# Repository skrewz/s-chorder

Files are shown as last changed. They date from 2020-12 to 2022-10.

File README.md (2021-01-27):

# s-chorder

This is a [chording keyboard project](https://en.wikipedia.org/wiki/Chorded_keyboard). In short, it's a device that allows you to type one-handed and with minimal movement.

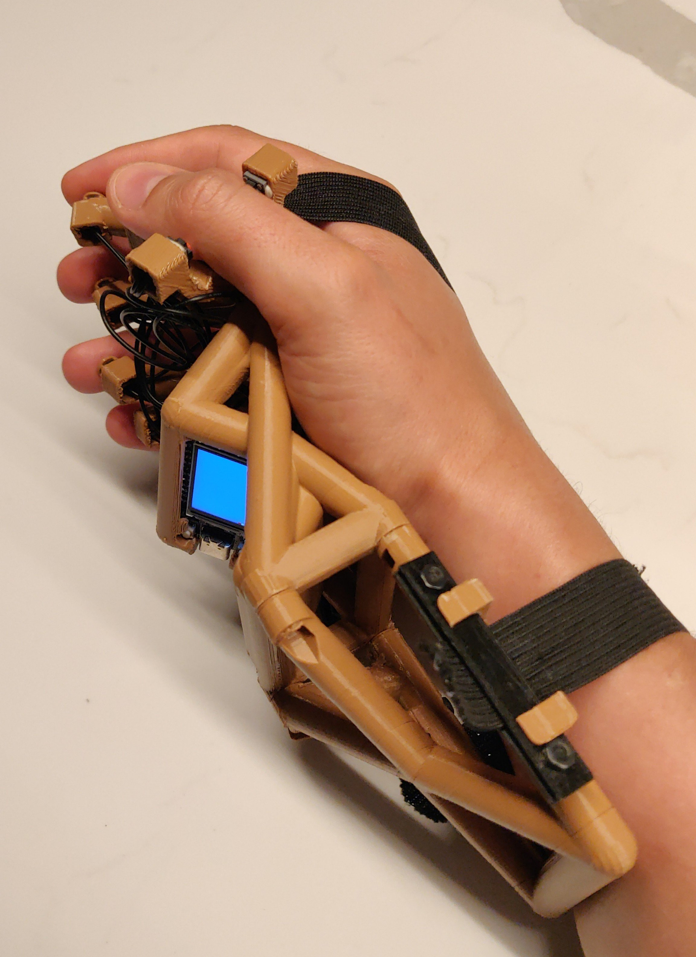
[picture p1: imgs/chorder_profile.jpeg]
chorder_profile Chorder in profile


## Why?

Chording keyboards fill certain niches.

* They are perfect for wearable computing which [Greg Priest-Dorman has practised for a number of years](https://www.cs.vassar.edu/people/priestdo/wearables/top). Indeed, his and [Mikkel Holm Olsen's SpiffChorder](https://chorder.cs.vassar.edu/doku.php?id=spiffchorder:hardware) served as inspiration for this project.
* They allow usage in the blind. This opens up for certain use cases, including note taking in the dark and in situations calling for inconspicuousness (if you can get past the bit about having something attached to your hand, that is).
* They can aid people with RSI related injuries by providing an alternative typing system, or a system that makes use of a remaining limb.

# How would I go about making one myself?

The model OpenSCAD file [is parametric to a ridiculous degree](https://github.com/skrewz/s-chorder/blob/master/chorder.scad#L33-L71). The idea is that one is supposed to be able to plop one's own measurements into it, and it'd generate a 3D model that fits a hand with such measurements. We may, however, have strayed from that ideal at this point, and yours truly, by the nature of things, has only had the need to produce models for one specific geometry.

If you find yourself trying this out, I'd recommend one of two approaches, or a combination of them:

1. Try measuring your finger segment lengths. They are measured on a bent finger (i.e. one that exposes 90 degree angles on both ends of the segment) and measured like a caliper would; externally. The finger radii should handle the difference from external measurement to where the joint pivots. This might provide a starting point, but, ultimately, you'll also be...:
2. Find some economic slicing settings for your slicer and acknowledge you will get it wrong. I find that it's worth printing another version even for single millimetres of incorrect location, so it pays to print a whole lot of single-shelled-5%-infill sorts of budget prints.

At any rate, make sure you make a git commit in your fork for every time you print a prototype. This'll help greatly in terms of knowing what you've changed. And please let me know what sort of tweaks you've had to do—maybe it can be better integrated into the model's calculations.

## Actually printing it

The `finger_end` will need a lot of support. It's essentially printed on supports. I've had good mileage with two raft layers and playing with Prusa-Slic3r's support enforcers.

The `body` and `wrist_handle` can be printed standing on their connecting surfaces, although the `body` is likely to need a fair bit of support for the bits that eventually will be under the index finger.

The `body` and `finger_end` modules derive their connection points from the same finger geometry measurements, so if they change, you'll likely need to print a new version of both. The `wrist_handle` module is fairly fixed and won't need much fine-tuning.

## Electronics and firmware

I would recommend using a TTGO T-Display for this project. It has battery capability, charges off USB-C and allows some nice features surrounding note-taking. I bought [this product for the project](https://www.aliexpress.com/item/1005001343590866.html).

The model is based on 6mm×6mm buttons (seemingly for computer mice?). I used [these ones from AliExpress](https://www.aliexpress.com/item/32653516999.html). The straps are made from the elastic/silicone tape that's meant to be sown into garments for invisible hold. You'll probably also want to solder some long-ish Dupont cables.

I've developed [a firmware for my purposes](https://github.com/skrewz/esp-idf-chorderfw). It's a bit of a work in progress, though.

# Contact

Well. My email address is in the git commit history, right? 🙂

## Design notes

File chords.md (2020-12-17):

# Chord overview

This is laid out for reading for right-hand chorders. It applies in reverse, too.

## Letters and their extra functions

Shifting [F], numbering [N] and "both" are prefix chords. If pressing [CN] together isn't convenient, one can do [N][F] or [F][N], which may be more appropriate for certain hardware.

Empty spots below may have functions; they're omitted because those are better done by other chords.

None    | shifted     | Num  | Both  | Thumb  | Fingers | Hint
--------|-------------|------|-------|--------|---------|-----
[]      | [F]         | [N]  | [CN]  | F C N  | I M R P |
[space] | [space]     | 1    | !     | ◻◼◻    | ◻◻◻◻    |
a       | A           | +    |       | ◻◼◻    | ◼◼◼◻    | **A**ddition
b       | B           | \    | &#124;| ◻◻◻    | ◼◻◻◼    | **B**ackslash
c       | C           | 7    | &     | ◻◼◻    | ◻◼◻◻    |
d       | D           | /    | ?     | ◻◻◻    | ◼◼◻◻    | **D**ivision
e       | E           | =    | +     | ◻◻◻    | ◼◼◼◻    | **E**qual
f       | F           | 9    | (     | ◻◼◻    | ◻◻◻◼    |
g       | G           | 8    | *     | ◻◼◻    | ◻◻◼◻    |
h       | H           | 00   |       | ◻◻◻    | ◻◼◼◻    |
i       | I           | 2    | @     | ◻◻◻    | ◼◻◻◻    |
j       | J           | ()   | ()    | ◻◼◻    | ◼◻◼◻    |
k       | K           | $    | $     | ◻◻◻    | ◼◻◼◻    |
l       | L           | 6    | ^     | ◻◼◻    | ◼◻◻◻    |
m       | M           | *    | *     | ◻◼◻    | ◼◼◻◻    | **M**ultiply
n       | N           |      |       | ◻◼◻    | ◻◼◼◼    |
o       | O           | 0    | )     | ◻◼◻    | ◼◼◼◼    | Zer**o**
p       | P           | %    | %     | ◻◼◻    | ◻◼◼◻    | **P**ercent
q       | Q           | ?    | ?     | ◻◼◻    | ◼◻◼◼    | **Q**uestion
r       | R           | 3    | #     | ◻◻◻    | ◻◼◻◻    |
s       | S           | -    | _     | ◻◻◻    | ◻◼◼◼    | **S**ubtraction
t       | T           | 000  | 000   | ◻◻◻    | ◼◼◼◼    | 
u       | U           | " "  | " "   | ◻◻◻    | ◻◻◼◼    | Two quotation marks and a back-arrow
v       | V           |      |       | ◻◼◻    | ◻◻◼◼    |
w       | W           | 5    |       | ◻◻◻    | ◻◻◻◼    |
x       | X           | &    | &     | ◻◼◻    | ◼◻◻◼    | (an ampersand has a little **x** in it?)
y       | Y           | 4    |       | ◻◻◻    | ◻◻◼◻    |
z       | Z           | `    | ~     | ◻◻◻    | ◼◻◼◼    |

## Common punctuation

None    | Shifted     | Thumb  | Fingers | Hint
--------|-------------|--------|---------|-----
[]      | [F]         | F C N  | I M R P |
;       | :           | ◻◻◼    | ◻◻◼◼    |
,       | <           | ◻◻◼    | ◻◼◻◻    | **C**omma
.       | >           | ◻◻◼    | ◻◼◼◻    | **P**eriod
'       | "           | ◻◻◼    | ◼◼◼◻    | **A**postrophy
(       |             | ◻◻◻    | ◼◼◻◼    |
[       |             | ◻◼◻    | ◼◼◻◼    |
{       |             | ◻◻◼    | ◼◼◻◼    |
)       |             | ◻◻◻    | ◻◼◻◼    |
]       |             | ◻◼◻    | ◻◼◻◼    |
}       |             | ◻◻◼    | ◻◼◻◼    |

## Media control

None    | Shifted     | Thumb  | Fingers | Hint
--------|-------------|--------|---------|-----
[]      | [F]         | F C N  | I M R P |
🕪       |             | ◼◼◻    | ◻◻◼◼    |
🕩       |             | ◼◼◻    | ◼◼◻◻    |
⏹️       |             | ◼◼◻    | ◻◼◻◻    |
⏯️￼      |             | ◼◼◻    | ◻◼◼◻    |
⏭️￼      |             | ◼◼◻    | ◻◼◼◼    |
⏮️￼      |             | ◼◼◻    | ◼◻◻◼    |
⏮️￼      |             | ◼◼◻    | ◼◼◼◻    |

## Common special keys

(It is possible to obtain numpad equivalents with a [CF] prefix, but ignored for now.)

Plain        | Thumb  | Fingers | Hint
-------------|--------|---------|-----
[]           | F C N  | I M R P |
`Enter`      | ◼◻◻    | ◻◻◻◼    |
`Backspace`  | ◼◻◻    | ◻◼◻◻    |
←            | ◼◻◻    | ◼◻◻◻    |
↓            | ◼◻◻    | ◻◻◼◼    |
↑            | ◼◻◻    | ◼◼◻◻    |
→            | ◼◻◻    | ◻◻◼◻    |
`Home`       | ◼◻◻    | ◼◻◼◼    |
`End`        | ◼◻◻    | ◼◻◻◼    |
`Tab`        | ◼◻◻    | ◼◻◼◻    |
`Left shift` | ◼◻◻    | ◻◻◻◻    |
`Caps lock`  | ◼◻◻    | ◼◼◼◼    |
`Page up`    | ◼◻◻    | ◼◼◼◻    |
`Page down`  | ◼◻◻    | ◻◼◼◼    |

## Common mode-setting/miscellanea chords

Plain          | Thumb  | Fingers | Note
---------------|--------|---------|-----
[]             | F C N  | I M R P |
`GUI`          | ◻◻◼    | ◼◻◼◻    | Prefix
`Esc`          | ◻◻◼    | ◻◻◼◻    | Not a prefix
`Ctrl`         | ◻◻◼    | ◼◻◼◼    | Prefix
`Alt`          | ◻◻◼    | ◻◼◼◼    | Prefix
`Insert`       | ◻◻◼    | ◼◻◻◼    | Not a prefix

## Less frequent special keys

Plain          | Thumb  | Fingers | Hint
---------------|--------|---------|-----
[]             | F C N  | I M R P |
`Delete`       | ◼◻◻    | ◻◼◼◻    |
`Scroll Lock`  | ◼◻◻    | ◼◼◻◼    |
`Print Screen` | ◼◻◻    | ◻◼◻◼    |
↖              | ◼◻◻    | ◼◻◼◼    |
↗              | ◼◻◻    | ◼◼◼◻    |
↘              | ◼◻◻    | ◻◼◼◼    |
↙              | ◼◻◻    | ◼◻◻◼    |
`Numlock`      | ◻◼◼    | ◼◼◼◼    |
Chorder reset  | ◼◼◼    | ◻◻◻◻    | Resets internal state of chorder
`F` key prefix | ◻◻◼    | ◻◻◻◼    |

# Acknowledgements

This is essentially the spiffchorder.

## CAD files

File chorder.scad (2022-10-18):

// TODO: Whole thing should be much more comprehensively commented
// TODO: test object should have contacts at weird angles
// TODO: test object should include connector_positive/connector_negative
// TODO: model should echo() absolute positions of buttons, relative to some
//       known point (connection point?)

partname = "composition";
// The Makefile scrapes the below, but you can specify partname to be any of
// the below values:
//
// _partname_values composition finger_end finger_l body wrist_handle test_object

/*****************************************************************************/
/* Likely calibration properties                                             */
/*****************************************************************************/

// finger_measurements
//
// For the below, the "first joint" (joint 0) is the one at the base of the
// finger. Most people thus have joints 0, 1 and 2 on their four fingers, and
// joints 0 and 1 on their thumb (I'm not exception).
//
// The "first segment" (segment 0) thus is between joint 0 and joint 1, etc,
// until segment 2, which ends at the tip of the finger (segment 1 in the case
// of a thumb).
//
// Generally, these are measured when joints are bent 90 degrees.
//
// E.g. to measure segment 0 on pinky, you'd clench your fist and look at it
// from below. That way, joint0 and joint1 on pinky will be at an angle of at
// least 90 degrees. Then you put a caliper on those two pinky joints.
//
// (It gets more finger-yoga-like to do this with other joints. You'll probably
// have to use another hand to hold the joint in a slightly overstretched
// position. Or take a guess.)
pinky_segment_lengths  = [ 53,  32, 38 ];
ring_segment_lengths   = [ 65,  40, 41 ];
middle_segment_lengths = [ 69,  44, 41 ];
index_segment_lengths  = [ 65,  39, 41 ];
thumb_segment_lengths  = [ 54,  40 ];

// Radii of each finger:
pinky_radius  =  7.5;
ring_radius   =  9.0;
middle_radius = 10.0;
index_radius  = 10.0;
thumb_radius  = 11.0;

// Angles at joint 0, joint 1 and joint 2, for a "comfortably glove-shaped" hand:
pinky_angles  = [20,37,33];
ring_angles   = [20,60,20];
middle_angles = [15,60,10];
index_angles  = [20,30,10];
thumb_angles  = [0,0];

// Almost-guesstimate: for a fingers-stretched hand, where are the joint 0's?
//
pinky_joint0_offset  = [ 110, -25,-15];
ring_joint0_offset   = [  89, -10,-10];
middle_joint0_offset = [  64,   0,  0];
index_joint0_offset  = [  32,  -2,  0];
thumb_joint0_offset  = [   5, -50,-40];

wristaxis_thumbside_upper_offset  = [  37, -80,-15];
wristaxis_pinkyside_upper_offset  = [  97, -80,-15];
wristaxis_radius = 20;

// four fingers: rotation around y axis:
pinky_joint0_rotation  =  [ 14, -30];
ring_joint0_rotation   = [   9, -10];
middle_joint0_rotation = [  -3,   0];
index_joint0_rotation  = [ -10,   0];
// thumb: rotation around x axis:
thumb_joint0_rotation  = [-110, -90];

// LiPo battery measurements:

lipo_compartment_wdh = [34+1,53+3.5,4.9+1];

// the girth of the riggers that make up the most of the finger mounts
frame_radius = 5;


button_l_thickness = 0.5;
button_l_thin_part_thickness = 0.5;
button_l_offset = 4;
button_l_cutout_thickness = button_l_thickness + 1;

// MCU related measurements:

// (Clearance in the height dimension has to be fairly generous if you're using
// Dupont cables.)
mcu_in_use = "TTGO T-Display";
mcu_wall_w = 1.5;
// Use to press MCU deeper (negative values) into its cutout:
mcu_vertical_indentation = -2;


// Elastic band width:

elastic_band_w = 20;
// measured as compressed, if relevant:
elastic_band_thickness = 1;
elastic_band_clearing_w = 22;
elastic_band_wall_w = 3;

button_hole_overdimension_factor = 1.15;

// how much to depress (in the z direction) contact_{positive,negative} given
// that the contact point is at z=0.
contact_z_depress = 15;
// how much depression of spring before electrical contact is made:
contact_clearance = 4;
// 0.3mm wire diameter 10 mm high 6mm outer diameter springs:
// https://www.aliexpress.com/item/33050149067.html
spring_radius = 3;
spring_height = 10;

// Do we want a GND connector on the body()?
include_gnd_connector = false;

/*****************************************************************************/
/* Less-likely calibration properties                                        */
/*****************************************************************************/



// real m3 radius:
m3_radius = 1.5;
// so that an m3 bolt can be passed through without too much effort:
m3_clear_radius = 1.7;

m3_bolt_visualisation_height = 26;

m3_head_radius = 3; // from memory
m3_head_clear_radius = 3.2; // from memory
m3_nut_clear_radius = 3.4; // When creating $fn=6 cutouts for these
m3_nut_height = 2; // actual height (for visualisation)
m3_nut_clear_height = 4; // When creating $fn=6 cutouts for these
m3_head_height = 2; // from memory
m3_nut_holder_wall_w = 1;


connector_depth = 2;

aux_connector_dimension = frame_radius;
aux_connector_growth_factor = 1.3;
aux_connector_growth_height = 10;
aux_connector_standoff = 7;

// https://www.aliexpress.com/item/32960278288.html
// measured: microswitch_box_wdh = [5.79,12.86,6.16];
microswitch_box_wdh = [5.80+0.4,12.80+0.4,/*choosing measured*/6.16];
// Visually only:
microswitch_box_black_until_h = 3.17;
// Switch expands a bit around the mounting through holes:
microswitch_box_h_at_throughhole = 6.52;
microswitch_pin_wdh = [0.5,0.8,3.18];
microswitch_pin_depths = [
  (12.80-2*5.15)/2,
  (12.80-2*5.15)/2+1*5.15,
  (12.80-2*5.15)/2+2*5.15
];
microswitch_lever_d = 1.42;
// only until the point under the radius; larger for cosmetic purposes
microswitch_lever_l = 14.50-5.00/2;
microswitch_lever_width = 3.6;
// estimate:
microswitch_lever_rest_angle = 20;
microswitch_lever_wheel_wr = [3,5.00/2];
// off the lever clearance:
microswitch_lever_wheel_raise = 1.00; // measured

microswitch_throughhole_r = 0.9; // crummy measurement; not precise
microswitch_throughholes_yzs = [
  [(microswitch_box_wdh[1]-6.50)/2,5.80-5.10],
  [(microswitch_box_wdh[1]-6.50)/2+6.50,5.80-5.10],
];

// the width of the pieces "holding up" the switch in its mount:
microswitch_support_bridge_width = 2;
microswitch_case_wall_w = 2;



// how far down (perspective of joint1 on the thumb) the connection point is placed:
thumb_connection_point_translation_distance = 2*thumb_radius;

// Derive coordinates and rotation vectors:

// Helper functions {{{

// These helper functions calculate the coordinate following a segment, as if
// *_joint0_rotation didn't exist (it can be compensated for, later on).
function x_coord_for(startvec,angle,segment,radius) =
  startvec[0] ; // always same, given no _joint0 rotation.
function y_coord_for(startvec,angle,segment,radius) =
  startvec[1] + cos(angle)*(segment-2*radius);
function z_coord_for(startvec,angle,segment,radius) =
  startvec[2] + sin(-angle)*(segment-2*radius);

function sum(list,i=0) = i<len(list)-1 ? list[i] + sum(list,i+1) : list[i];
assert(sum([ 4, 5, 3]) == 12);
assert(sum([ 4, 1, -1]) == 4);

function rotate_coord(coord,joint0_rotation,relative_to_joint0_offset) =
  [
    // have hypotenuse and angle, want opposite:
    relative_to_joint0_offset[0]-sin(joint0_rotation[0])*(relative_to_joint0_offset[2]-coord[2]),
    coord[1], // remains the same when rotating around y axis
    // have hypotenuse and angle, want adjacent:
    relative_to_joint0_offset[2]-cos(joint0_rotation[0])*(relative_to_joint0_offset[2]-coord[2])
  ];

function coord_for(startvec,angle,segment,radius) =
  [
    x_coord_for(startvec,angle,segment,radius),
    y_coord_for(startvec,angle,segment,radius),
    z_coord_for(startvec,angle,segment,radius)
  ];

// Returns a euler rotation 3-tuple that can be used to rotate something in the
// direction of the vector given:
function rotation_of_vector(v) =
  // {{{
  // Due to OpenSCAD function syntax, the below cannot have interim variables.
  // This was a previous calculation, for reference:
  //
  // rotation_upwards = atan(v[2])/sqrt(pow(v[0],2)+pow(v[1],2)));
  // tangent = (v[1])/(v[0]);
  // rotation_in_plane = atan(tangent) + (0 > (v[0]) ? 180 : 0);
  [
    0,
    90-atan((v[2])/sqrt(pow(v[0],2)+pow(v[1],2))),
    // possible corner case: what about _minus_ infinity?
    (is_num(atan(v[1]/v[0])) ? atan(v[1]/v[0]) + (0 > (v[0]) ? 180 : 0) : 90)
  ];
  // }}}

// Applies euler rotation 3-tuple rotations by way of matrix multiplication.
// This function's output is multiplied onto a vector of [0,0,length].
function rotation_for_euler_rotations(a) =
    [[cos(a[2]),-sin(a[2]),0],[sin(a[2]),cos(a[2]),0],[0,0,1]]
    * [[cos(a[1]),0,sin(a[1])],[0,1,0],[-sin(a[1]),0,cos(a[1])]]
    * [[1,0,0],[0,cos(a[0]),-sin(a[0])],[0,sin(a[0]),cos(a[0])]];

// }}}

// Assign {pinky,ring,middle,index,thumb}_{coords,rotation} {{{
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

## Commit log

2020-05-20 chorder.scad: actually just a hand model.
    [chorder.scad]
2020-05-20 Adding {pinky,...,thumb}_{coords,rotation}.
    Yikes.
    [chorder.scad]
2020-06-04 Somewhat connected finger_end() and body() modules.
    This needs to get expanded with a wrist_holder() or somesuch.
    [chorder.scad]
2020-06-10 Incremental evolution. Mostly a ready version.
    This is pending various pre-production tweaks and re-measurements, at
    least.
    [chorder.scad]
2020-06-21 Slimmer wrist, bulked contact, elastic clip, BYO MCU cutout.
    Also, various tweaks from early full prototypes.
    [chorder.scad]
2020-06-21 Visualise bolt action better.
    [chorder.scad]
2020-06-21 thumb_contact -> thumb_contact_{positive,negative}.
    [chorder.scad]
2020-06-21 MCU cutout tweaking for Adafruit Feather 32u4 BLE.
    [chorder.scad]
2020-06-21 Smaller thumb radius. Apparently my thumb isn't that big. 🤷
    [chorder.scad]
2020-06-21 The MCU was rotated around.
    [chorder.scad]
2020-06-21 The LiPo compartment was added.
    [chorder.scad]
2020-06-21 GND connector added.
    (The user's hand touches metal to create conductivity. This is the
    opposite end of the circuit.)
    [chorder.scad]
2020-06-26 Refactor the rotation calculation out.
    (Will need this separately soon.)
    [chorder.scad]
2020-06-26 Adding elastic clips and clasps to the body().
    This will ensure a tight hold on the hand onto frame. Too much movement,
    otherwise.
    The free parts of the clasps need to be rendered separately to the
    places they attach. That's for later.
    [chorder.scad]
2020-07-22 Slight adjustments to placements.
    [chorder.scad]
2020-08-02 Updates to test_object().
    [chorder.scad]
2020-09-19 Moving clasps/clips out of the way
    It's okay for the front clip to be fairly far back the back of the hand.
    It'll probably hold in place regardless.
    [chorder.scad]
2020-09-20 Adding buttonbased contact_*()'s
    [chorder.scad]
2020-09-20 Slight adjustments to buttonbased contact + test object
    [chorder.scad]
2020-09-20 Making GND connector optional
    [chorder.scad]
2020-09-20 remove trailing space + linting
    [chorder.scad]
2020-09-20 Adding skeletal which_part functionality
    Also adding linting for it.
    [chorder.scad]
2020-09-20 Add printable modes for all sub-objects
    [chorder.scad]
2020-09-22 Much more contact_clearance
    This'll make the buttons protrude above their holes, making them easier
    to find and engage.
    [chorder.scad]
2020-09-27 Rotate pinky, no more shrouds and more angle on ring
    (This is a hackish interim commit. A print of this however turned out
    useful, so for history, keeping it.)
    [chorder.scad]
2020-09-27 Interim: refactored two-dimensional joint0 rotation
    [chorder.scad]
2020-09-27 Implements second dimension of joint0 rotation
    [chorder.scad]
2020-09-27 Gets rid of extraneous part of outrigger
    [chorder.scad]
2020-09-29 Make compass() take length parameter
    [chorder.scad]
2020-09-29 Move clasps and clips around on finger_end/body
    [chorder.scad]
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2020-10-21 rotate mcu and update battery size
    Will be rotating battery next, presumably.
    [chorder.scad]
2020-10-21 Tighter location of pinkyside_clip
    [chorder.scad]
2020-10-21 Also rotate illustration
    [chorder.scad]
2020-10-21 Rotate lipo battery into place
    [chorder.scad]
2020-10-22 Measurement tweaks for TTGO T-Display
    [chorder.scad]
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2020-12-17 Adding an initial version of an aux connector
    (This, in particular, is intended for holding a book holder.)
    [chorder.scad]
2020-12-17 Adding front elastic clip parking position
    [chorder.scad]
2020-12-18 Allow clips to be printed without the clips
    [chorder.scad]
2021-01-04 L-shaped button shields, v1
    [chorder.scad]
2021-04-27 Make clip have center bolt and nut
    Also make clips a bit countersunk
    [chorder.scad]
2022-01-25 Adding finger_l's
    This makes for a larger interface surface with the buttons. Kind of adds
    value through the increased force one tends to apply.
    [chorder.scad]
2022-01-26 Adding a microswitch() module for subsequent inclusion
    [chorder.scad]
2022-01-26 Make microswitch_* global
    [chorder.scad]
2022-01-26 Actually place the microswitch illustration
    (Then onwards to placing the holder and cutouts that'll put it there.)
    [chorder.scad]
2022-01-31 Adding microswitch based contact_{posi,nega}tive
    [chorder.scad]
2022-02-15 chore: whitespace
    [chorder.scad]
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2022-03-01 Adding makefile for `make -j` goodness
    [chorder.scad]
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2022-03-03 Allow chorder to rest on display mount
    [chorder.scad]
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2022-03-04 Adding a stand and magnet holder
    This allows the chorder to be stood up on its back and hung on metallic
    wall surfaces.
    [chorder.scad]
2022-04-17 Moving thumbside clasp support to fit bolt
    [chorder.scad]
2022-04-17 Slightly larger clearance for microswitch_box_wdh
    [chorder.scad]
2022-04-17 Add tension relief member
    [chorder.scad]
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2022-05-07 Making base stand upright better
    [chorder.scad]
2022-05-07 Adding magnet mounts
    This allows the base of the chorder to be hung from metal frames etc.
    [chorder.scad]
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2022-05-07 Modifying location of elastic clasp
    [chorder.scad]
2022-05-07 Making lipo holder more open
    [chorder.scad]
2022-10-18 New battery; slightly enlarged MCU and USB cutouts
    [chorder.scad]
